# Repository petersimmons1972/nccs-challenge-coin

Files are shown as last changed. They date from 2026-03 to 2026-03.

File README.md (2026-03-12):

# NCCS 2026 Swim Team Challenge Coin

A 50mm, 4-color challenge coin for the **North Cobb Christian School 2026 Swim Team**, designed for single-print production on a Bambu P1S with AMS Pro 2. No glue. No assembly. One print, two faces.

| Obverse (Front) | Reverse (Back) |
|---|---|
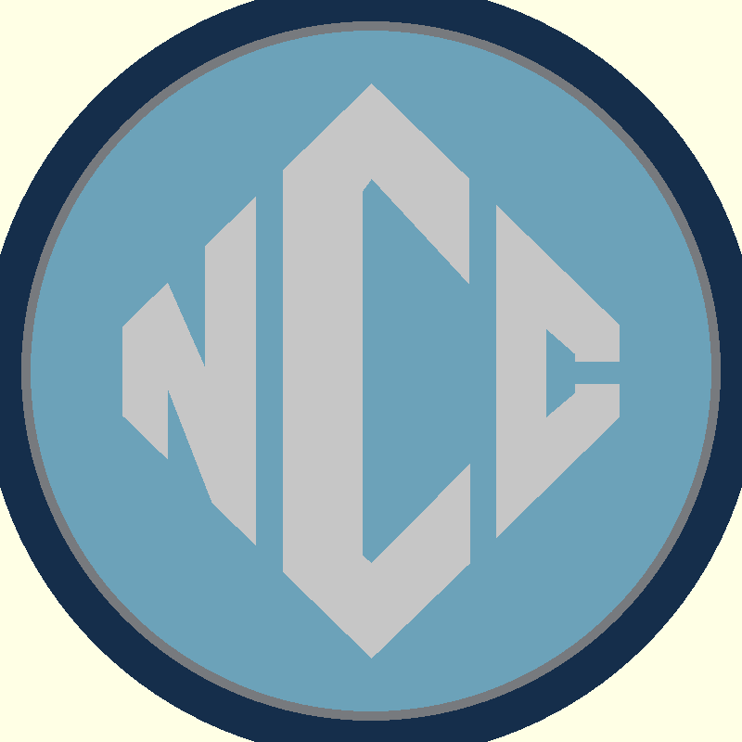
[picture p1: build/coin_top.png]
Obverse
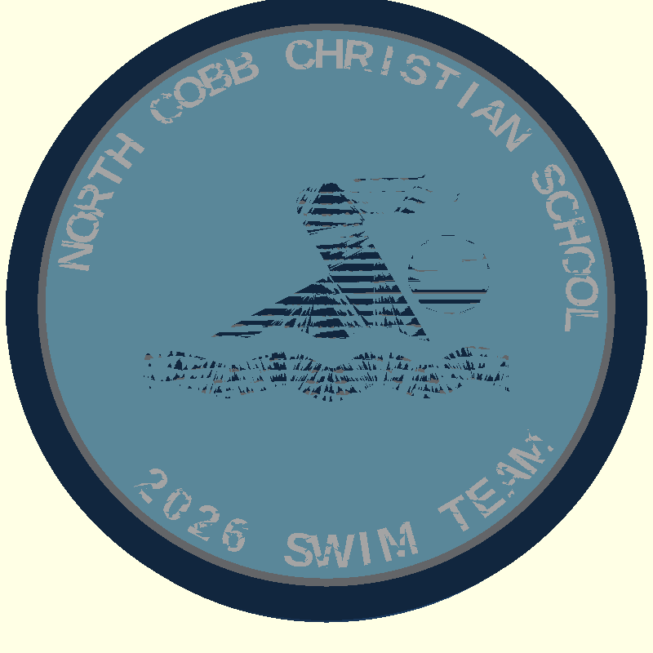
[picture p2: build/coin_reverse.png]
Reverse
|  |  |

---

## Design

### Obverse — NCC Shield Logo
The school's diamond shield in navy blue, surrounded by carolina blue field and a subtle gray accent ring.

- Navy blue diamond logo body
- White stylized NCC letterform inset into the diamond
- Carolina blue inner field
- Dark gray accent ring
- Navy blue outer rim

### Reverse — Swimmer + School Name
Swimmer silhouette over the school name arced in two directions.

- Navy swimmer silhouette centered in the carolina blue field
- **"NORTH COBB CHRISTIAN SCHOOL"** arced across the top in white
- **"2026 SWIM TEAM"** arced along the bottom in white
- Same gray accent ring and navy rim as obverse

---

## Colors

| AMS Slot | Color | Hex | Used On |
|---|---|---|---|
| 1 | Navy Blue | `#1B3B60` | Outer rim, obverse diamond, reverse swimmer |
| 2 | Dark Gray | `#999DA2` | Accent ring (swap for gold PLA to make it pop) |
| 3 | Carolina Blue | `#8BD1EE` | Inner field (both faces) |
| 4 | White | `#FFFFFF` | NCC letters (obverse), arc text (reverse) |

> **Tip:** Swapping slot 2 to a metallic gold PLA makes the accent ring stand out beautifully without any design changes.

---

## Specifications

| Parameter | Value |
|---|---|
| Diameter | 50 mm |
| Thickness | 5.0 mm |
| Relief height | 0.6 mm |
| Colors | 4 |
| Supports | None required |
| Layer height | 0.2 mm recommended |

---

## Print Instructions (Bambu Studio)

1. Open `build/NCCS_Challenge_Coin.3mf` in Bambu Studio 02.05+
2. Four filament slots auto-populate with correct color swatches
3. Assign your filaments:
   - Slot 1 → Navy Blue PLA
   - Slot 2 → Dark Gray PLA (or Gold for accent ring)
   - Slot 3 → Carolina Blue PLA
   - Slot 4 → White PLA
4. Print flat on build plate — no brim or supports needed

---

## File Structure

```
.
├── build.sh                  # Renders OpenSCAD → STL files + preview PNGs
├── create_3mf.py             # Packages STLs → Bambu-native 3MF
├── test_3mf.py               # TDD test suite (18 tests) for the 3MF builder
├── src/
│   ├── coin.scad             # Main double-sided coin model (all 4 colors)
│   ├── logo_diamond.svg      # Obverse: navy diamond body
│   ├── logo_border.svg       # Obverse: carolina border strokes
│   ├── logo_letters.svg      # Obverse: white NCC letterform
│   └── ref_swimmer.svg       # Reverse: swimmer silhouette
└── build/
    ├── coin_navy.stl         # Navy layer (rim + diamond + swimmer)
    ├── coin_gray.stl         # Gray layer (accent ring)
    ├── coin_carolina.stl     # Carolina layer (inner field, both faces)
    ├── coin_white.stl        # White layer (NCC letters + arc text)
    └── NCCS_Challenge_Coin.3mf  # Ready-to-print Bambu Studio project
```

---

## Rebuilding from Source

Requires [OpenSCAD](https://openscad.org/) and Python 3.

```bash
# Render all 4 color STLs + preview PNGs
./build.sh

# Package STLs into Bambu-native 3MF
python3 create_3mf.py

# Run the 3MF builder test suite
python3 -m pytest test_3mf.py -v
```

---

## Technical Notes

### Multi-Color Design: Zero Mesh Overlap

Each color layer is geometrically exclusive — no two meshes share any volume. The carolina blue base layer uses OpenSCAD `difference()` to subtract all other color shapes from itself. This prevents color bleed in the slicer.

### Double-Sided Single Print

Both the obverse and reverse are in one 5mm-thick coin body:
- **Obverse detail**: z = 4.4–5.0 mm (raised from the top face)
- **Reverse detail**: z = 0–0.6 mm (raised from the bottom face)

The coin prints once, flat on the build plate, with detail embossed on both faces.

### Reverse Face Mirroring

All reverse-face geometry is wrapped in `mirror([1, 0, 0])` in OpenSCAD so that logos and text read correctly when the coin is physically flipped over.

### Bambu Studio 3MF Format

The `.3mf` is built to Bambu's native spec:
- All 4 color meshes live in a single sub-model file (`3D/Objects/object_1.model`)
- Root model contains only an assembly wrapper with `p:path` component references
- `Application: BambuStudio-02.05.00.66` metadata triggers Bambu's native multi-color mode
- Filament colors are 6-digit hex in `Metadata/project_settings.config`

---

## Hardware Used

- Printer: Bambu P1S
- AMS: AMS Pro 2 (4 filament slots)
- Slicer: Bambu Studio 02.05.00.66

---

## Adapting for Your School

To customize this for a different school:

1. Replace the three logo SVGs in `src/` with your school's logo shapes
2. Adjust `logo_scale` in `coin.scad` if needed (current: `1.18` for 96 DPI SVGs)
3. Update the filament colors in `create_3mf.py` to match your school colors
4. Update the reverse arc text in `coin.scad` (`reverse_white_2d()`)

The swimmer SVG (`src/ref_swimmer.svg`) is from [UXWing](https://uxwing.com/swimming-icon/) and is free for personal and commercial use.

---

## License

This design is released for personal, non-commercial use. If you adapt it for another school or team, please share it back.

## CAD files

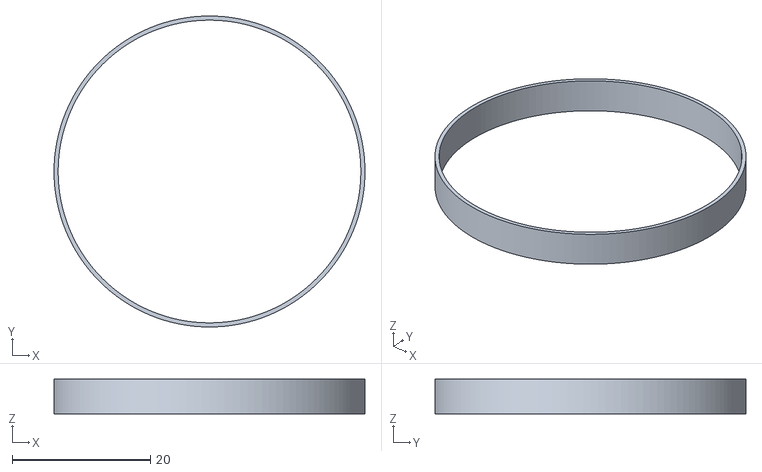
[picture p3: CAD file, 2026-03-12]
build/coin_gray.stl
45.0 x 45.0 x 5.00

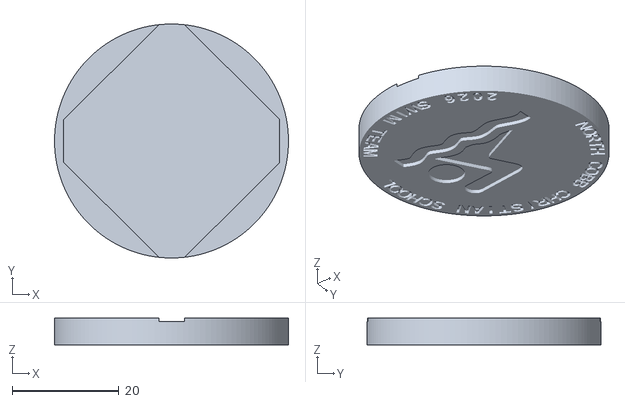
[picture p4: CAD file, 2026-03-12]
build/coin_carolina.stl
43.8 x 43.8 x 5.00

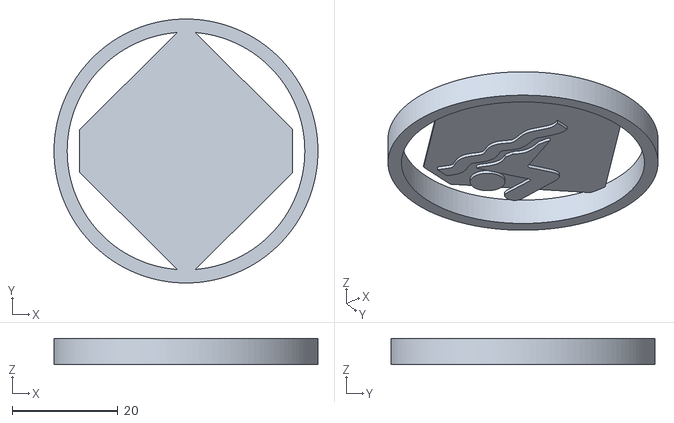
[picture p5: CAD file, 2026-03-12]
build/coin_navy.stl
50.0 x 50.0 x 5.00

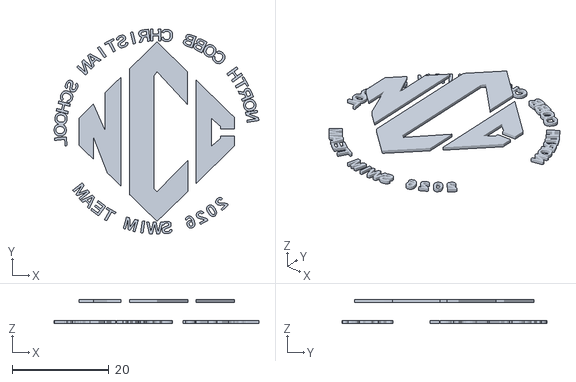
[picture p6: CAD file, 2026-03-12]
build/coin_white.stl
42.3 x 42.3 x 5.00

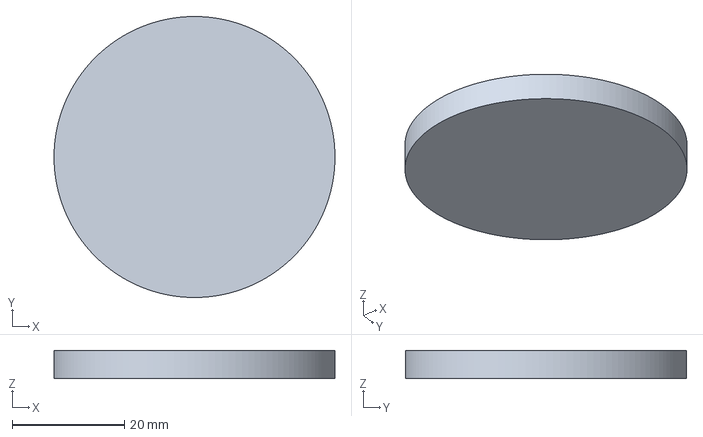
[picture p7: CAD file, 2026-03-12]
build/NCCS_Challenge_Coin.3mf
50.0 x 50.0 x 5.00 mm

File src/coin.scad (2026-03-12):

// NCCS Swim Team Challenge Coin - DOUBLE-SIDED
// Single print, no glue. Bambu P1S + AMS Pro 2 (4 colors)
//
// Top = Obverse (NCC shield logo)
// Bottom = Reverse (swimmer + arc text)
//
// IMPORTANT: Each color part has NO overlap with any other.
// Carolina blue base has all other colors subtracted from it.
//
// COLOR selects which filament layer to render:
//   0 = All (preview)
//   1 = Navy Blue (#1B3B60)
//   2 = Dark Gray (#999DA2) - accent ring only
//   3 = Carolina Blue (#8BD1EE)
//   4 = White (#FFFFFF)

COLOR = 0;

// === DIMENSIONS ===
coin_d = 50;
total_h = 5.0;       // Total coin thickness
rim_w = 2.5;
accent_w = 0.6;
relief = 0.6;        // Height of raised/recessed details

// Derived
inner_r = coin_d/2 - rim_w;
field_r = inner_r - accent_w;
text_r = field_r - 2;

// Logo scale (accounts for OpenSCAD 96 DPI SVG import)
logo_scale = 1.18;

// === COLORS ===
navy = [0.106, 0.231, 0.376];
gray = [0.6, 0.616, 0.635];
carolina = [0.545, 0.820, 0.933];
white_c = [1.0, 1.0, 1.0];

// === TEXT MODULES ===
module arc_text(str, radius, size, start_angle, char_angle) {
    for (i = [0:len(str)-1]) {
        angle = start_angle - i * char_angle;
        rotate([0, 0, angle])
            translate([0, radius, 0])
                text(str[i], size=size, font="Arial:style=Bold",
                     halign="center", valign="center");
    }
}

// Bottom arc text — characters at bottom half of circle, readable face-on.
module bottom_arc_text(str, radius, size, start_angle, char_angle) {
    for (i = [0:len(str)-1]) {
        angle = start_angle + i * char_angle;
        translate([radius * sin(angle), -radius * cos(angle), 0])
            rotate([0, 0, angle])
                text(str[i], size=size, font="Arial:style=Bold",
                     halign="center", valign="center");
    }
}


// =================================================================
// OBVERSE DESIGN (top face) - 2D shapes
// =================================================================

module obverse_navy_2d() {
    scale([logo_scale, logo_scale])
        import("logo_diamond.svg", center=true);
}

module obverse_carolina_2d() {
    scale([logo_scale, logo_scale])
        import("logo_border.svg", center=true);
}

module obverse_white_2d() {
    scale([logo_scale, logo_scale])
        import("logo_letters.svg", center=true);
}

// =================================================================
// REVERSE DESIGN (bottom face) - 2D shapes
// =================================================================

// Navy swimmer silhouette (bottom face)
module reverse_navy_2d() {
    mirror([1, 0, 0])
        translate([0, 1]) scale([0.65, 0.65])
            import("ref_swimmer.svg", center=true);
}

// White arc text only (bottom face)
module reverse_white_2d() {
    mirror([1, 0, 0]) {
        // Top arc: "NORTH COBB CHRISTIAN SCHOOL"
        arc_text("NORTH COBB CHRISTIAN SCHOOL",
                 radius=text_r, size=2.6,
                 start_angle=81, char_angle=6.8);

        // Bottom arc: "2026 SWIM TEAM"
        bottom_arc_text("2026 SWIM TEAM",
                        radius=text_r, size=2.6,
                        start_angle=-42, char_angle=7.2);
    }
}

// =================================================================
// 3D SHAPES for each color detail (used for both rendering AND subtraction)
// =================================================================

// Navy obverse diamond (top face)
module navy_diamond_3d() {
    translate([0, 0, total_h - relief])
        linear_extrude(height=relief)
            obverse_navy_2d();
}

// Navy swimmer (bottom face)
module navy_swimmer_3d() {
    linear_extrude(height=relief)
        reverse_navy_2d();
}

// Carolina obverse borders (top face)
module carolina_borders_3d() {
    translate([0, 0, total_h - relief + 0.01])
        linear_extrude(height=relief * 0.7)
            obverse_carolina_2d();
}

// White obverse letters (top face)
module white_obverse_3d() {
    translate([0, 0, total_h - relief])
        linear_extrude(height=relief)
            obverse_white_2d();
}

// White reverse text (bottom face)
module white_reverse_3d() {
    linear_extrude(height=relief)
        reverse_white_2d();
}

// =================================================================
// COLOR LAYER GEOMETRY - NO OVERLAP between parts
// =================================================================

// 1. NAVY: rim ring + obverse diamond + reverse swimmer
module navy_parts() {
    color(navy) {
        // Outer rim ring
        difference() {
            cylinder(h=total_h, d=coin_d, $fn=128);
            translate([0, 0, -0.01])
                cylinder(h=total_h+0.02, r=inner_r, $fn=128);
        }
        // Obverse diamond on top
        navy_diamond_3d();
        // Swimmer on bottom
        navy_swimmer_3d();
    }
}

// 2. GRAY: accent ring only
module gray_parts() {
    color(gray) {
        difference() {
            cylinder(h=total_h, r=inner_r, $fn=128);
            translate([0, 0, -0.01])
                cylinder(h=total_h+0.02, r=field_r, $fn=128);
        }
    }
}

// 3. CAROLINA: inner field with ALL other detail parts subtracted out
module carolina_parts() {
    color(carolina) {
        difference() {
            union() {
                // Base inner field cylinder
                cylinder(h=total_h, r=field_r, $fn=128);
                // Carolina borders on top
                carolina_borders_3d();
            }
            // Subtract navy diamond from top
            navy_diamond_3d();
            // Subtract navy swimmer from bottom
            navy_swimmer_3d();
            // Subtract white letters from top
            white_obverse_3d();
            // Subtract white text from bottom
            white_reverse_3d();
        }
    }
}

// 4. WHITE: obverse letters + reverse arc text
module white_parts() {
    color(white_c) {
        white_obverse_3d();
        white_reverse_3d();
    }
}

// === RENDER ===
if (COLOR == 0) {
    navy_parts();
    gray_parts();
    carolina_parts();
    white_parts();
} else if (COLOR == 1) {
    navy_parts();
} else if (COLOR == 2) {
    gray_parts();
} else if (COLOR == 3) {
    carolina_parts();
} else if (COLOR == 4) {
    white_parts();
}

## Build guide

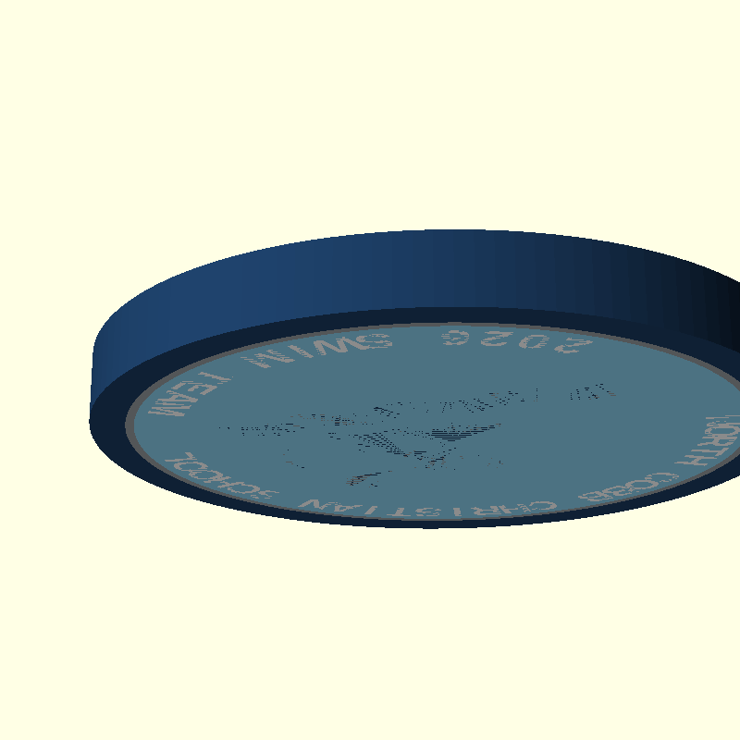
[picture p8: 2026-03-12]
build/coin_bottom_preview.png

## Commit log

2026-03-12 feat: initial commit — NCCS 2026 swim team challenge coin v3
    50mm 4-color challenge coin for North Cobb Christian School.
    Single print, double-sided. Designed for Bambu P1S + AMS Pro 2.
    - Obverse: NCC shield logo (navy diamond, white letters, carolina field)
    - Reverse: Navy swimmer silhouette, white arc text, gray accent ring
    - Bambu-native 3MF with correct extruder assignments
    - 18 TDD tests validating 3MF structure
    - Zero mesh overlap — geometrically exclusive color layers
    [NCCS_Challenge_Coin.3mf, coin.scad, coin_carolina.stl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]
2026-03-12 chore: remove proprietary files from public repo
    - Remove school logo SVGs (logo_diamond, logo_border, logo_letters) —
    these contain NCCS branding IP, not for public redistribution
    - Remove CLAUDE.md (personal AI config, internal paths)
    - Add both to .gitignore
    - Update README with instructions for adapting to other schools
    - Swimmer SVG (UXWing, free license) stays — noted in README
